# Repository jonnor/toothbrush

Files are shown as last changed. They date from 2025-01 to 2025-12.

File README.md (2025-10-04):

# Automatic toothbrush timer

This toothbrush timer tracks how long you spend on actively brushing your teeth.
It uses an accelerometer to measure motion, and analyzes it using a simple machine learning model.
The device helps you get to the 2 minute mark, which is the recommend duration!

This is a demo project for [emlearn-micropython](https://github.com/emlearn/emlearn-micropython),
a library efficient Machine Learning and Digital Signal Processing for [MicroPython](https://micropython.org/).
The intent is to be a fun and simple, but realistic application, of machine learning on microcontrollers,
in the area of Human Activity Recognition.

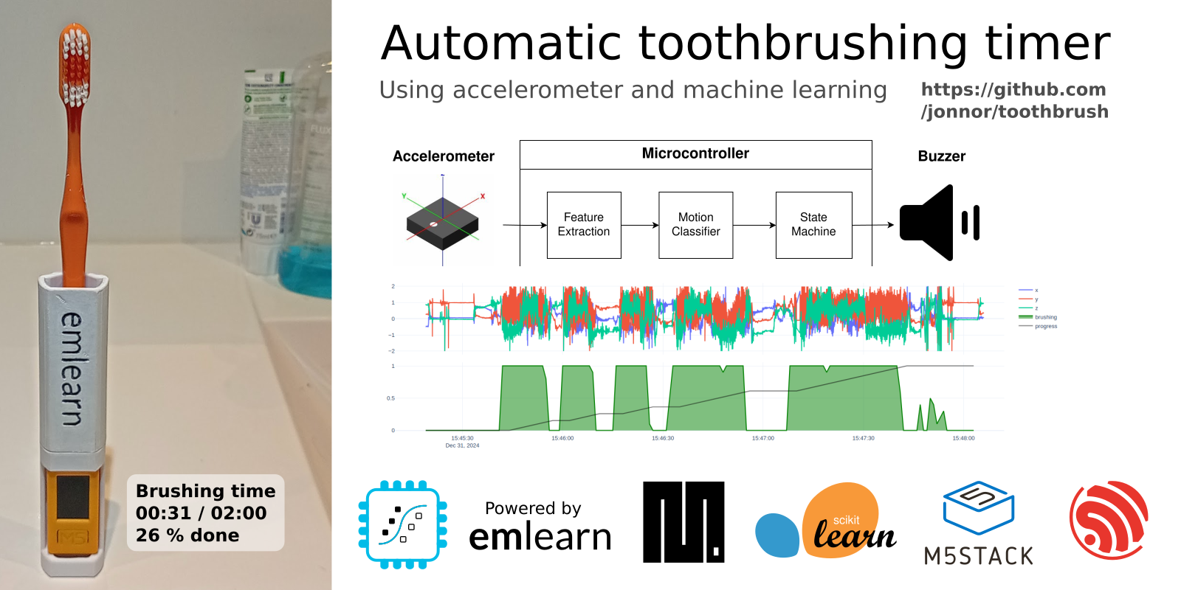
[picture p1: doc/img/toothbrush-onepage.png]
One-page visual explainer


## In use

Here is a [short demo video](https://www.youtube.com/shorts/U8TeewQ9t-k).

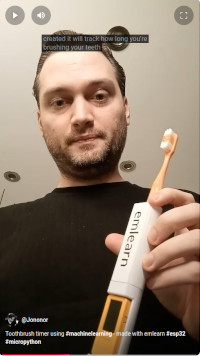
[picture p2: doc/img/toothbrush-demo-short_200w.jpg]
Demo video (https://www.youtube.com/shorts/U8TeewQ9t-k)


## Status
***Proof of Concept***. Tested working on device.

- Firmware is complete and functional
- Basic documentation on how to reproduce exists
- Software and training pipeline *needs some cleanup*

For more details, see [TODO.md](./doc/TODO.md)

## License
MIT

## Hardware

To assemble the device, one needs the following.

- [M5Stick C PLUS2](https://shop.m5stack.com/products/m5stickc-plus2-esp32-mini-iot-development-kit) from M5Stack
- 3d-printed toothbrush holder. [.STL export](mechanics/toothbrush-handle-print.stl) | [FreeCAD project](mechanics/toothbrush-handle.FCStd)
- Zipties
- Double-sided tape

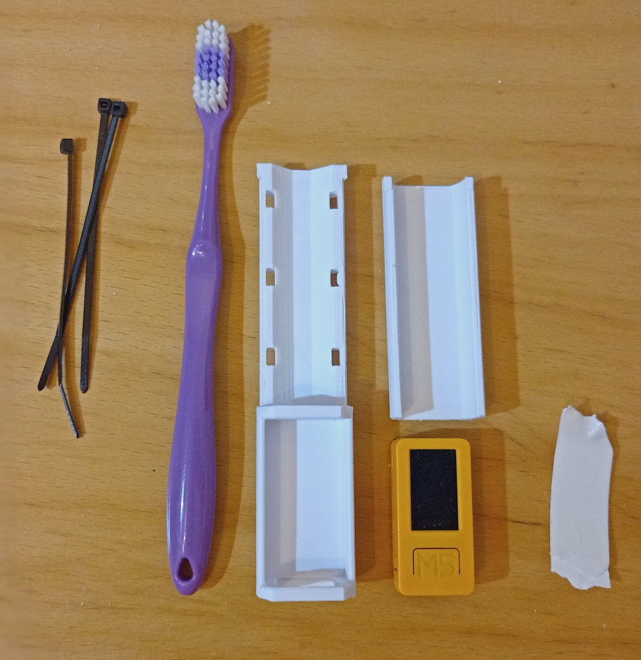
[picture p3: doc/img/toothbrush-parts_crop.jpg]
Parts before assembly
.

#### Stand

There is also an optional stand for a magnetic charging connector.
It uses a [Plexgear Magnetic USB-C adapter](https://www.kjell.com/no/produkter/kabler-og-kontakter/usb-kabler/plexgear-magnetisk-usb-c-adapter-p44923).
Hopefully something similar can be found online.

[FreeCAD project](mechanics/toothbrush-stand.FCStd)

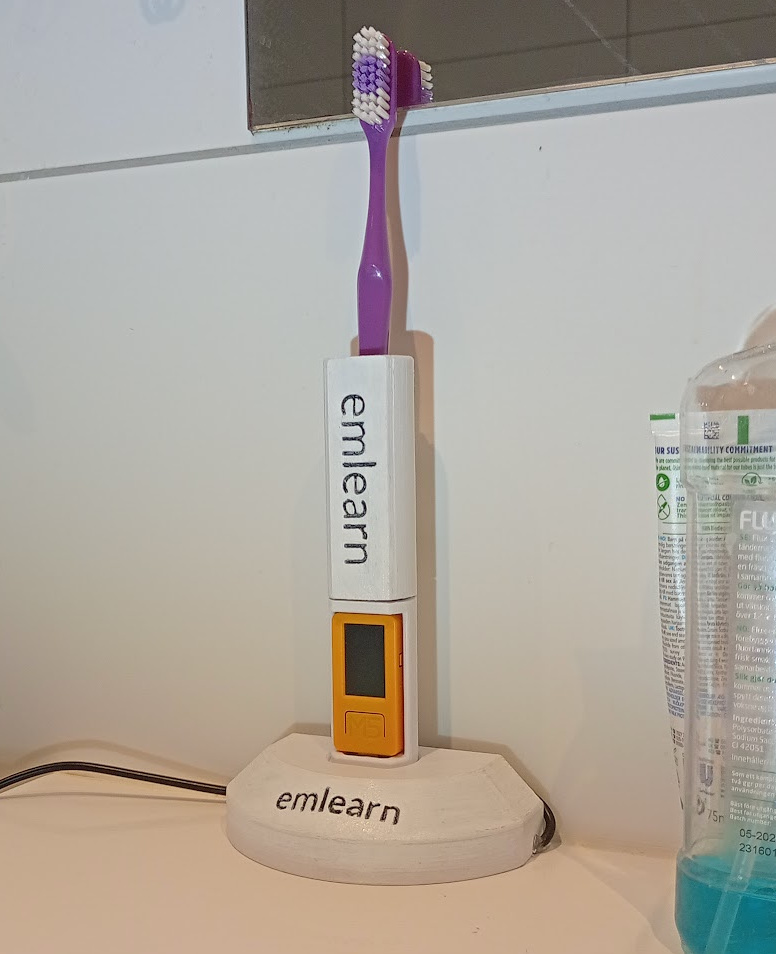
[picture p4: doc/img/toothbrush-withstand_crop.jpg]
Toothbrush with stand
.

## How it is built

The code that runs on device is found in [firmware/](./firmware).
The code used on PC to train machine learning model is found in [software/](./software)

#### Data recording

To record data we used the `har_record.py` script from [emlearn-micropython har_trees example](https://github.com/emlearn/emlearn-micropython/tree/master/examples/har_trees). 
We also recorded video of the brushing activity using a mobile phone.
This was used to establish the ground truth.
See [doc/data_collection.md](doc/data_collection.md) for details.

The raw data from device is stored in `data/jonnor-brushing-1/har_record/`.

#### Data labeling

We use [Label Studio](https://labelstud.io) to annotate the videos.
The labeling annotation definition can be found in [doc/labeling.xml](doc/labeling.xml).

The labeled data should be exported as .CSV file.

#### Data set preparation

When the data recording and data labeling has been completed, the data can be combined into a dataset.

```
FIXME: clean up these steps. Move from notebooks into .py files
```

The output goes to `data/jonnor-brushing-1/combined.parquet`.

#### Model training

To train the model we used the `har_train.py` script from [emlearn-micropython har_trees example](https://github.com/emlearn/emlearn-micropython/tree/master/examples/har_trees).
```
MIN_SAMPLES_LEAF=0.20,0.30 python har_train.py --dataset toothbrush_jonnor --window-length 50 --window-hop 50
```

#### Firmware

The firmware has the following overall architecture:

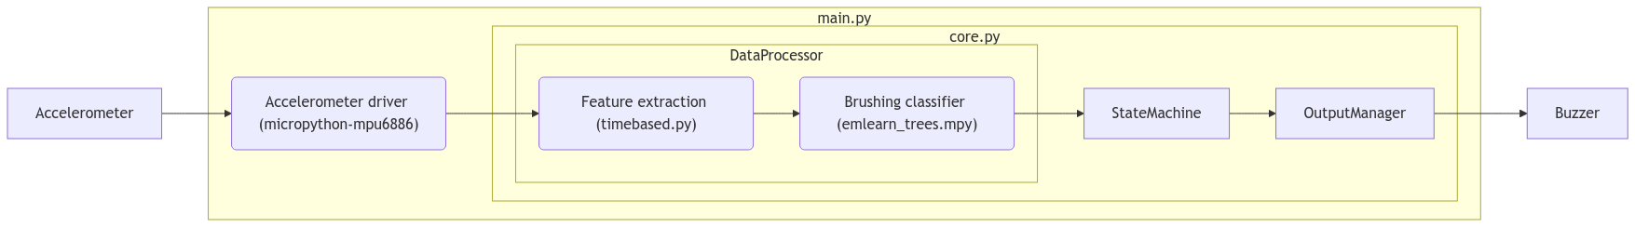
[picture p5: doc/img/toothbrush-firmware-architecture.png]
Firmware architecture diagram


Here is the states of the state machine, that defines the overall behavior of the device:
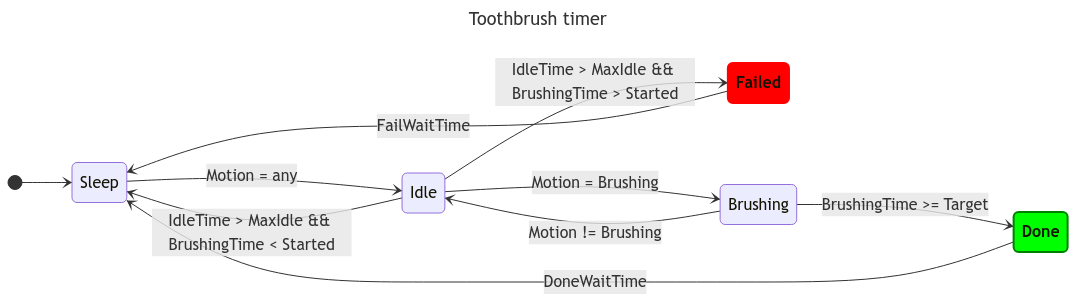
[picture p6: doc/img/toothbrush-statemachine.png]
State machine diagram


## Installing

#### Development environment

You must have Python 3.10+ installed.
Using a virtual environment is recommended.

Install project dependencies

```
pip install -e .
```

## For M5Stack M5Stick C PLUS 2 

Flash device with MicroPython for ESP32

```
mpflash flash --version 1.24
```

Copy dependencies to device

```
mpremote mip install https://emlearn.github.io/emlearn-micropython/builds/master/xtensawin_6.3/emlearn_trees.mpy
mpremote mip install github:jonnor/micropython-npyfile
mpremote mip install github:jonnor/micropython-mpu6886
mpremote mip install https://github.com/emlearn/emlearn-micropython/raw/refs/heads/master/examples/har_trees/timebased.py
mpremote mip install https://github.com/emlearn/emlearn-micropython/raw/refs/heads/master/examples/har_trees/recorder.py
```

## For XIAO BLE Sense NRF52840 

Flash device with MicroPython

```
TODO: provide pre-built firmware
```

Copy dependencies to device
```
mpremote mip install --target lib github:jonnor/micropython-npyfile
mpremote mip install --target lib https://github.com/emlearn/emlearn-micropython/raw/refs/heads/master/examples/har_trees/timebased.py
mpremote mip install --target lib https://github.com/emlearn/emlearn-micropython/raw/refs/heads/master/examples/har_trees/recorder.py
mpremote cp firmware/lsm6ds.py :lib/
```

#### Copy application to device

Copy the firmware files
```
mpremote cp firmware/core.py firmware/buzzer_music.py firmware/process.py firmware/brushing.trees.csv firmware/main.py :
```

Start the application and observe log
```
mpremote run firmware/main.py
```

Restart device, will disconnect log
```
mpremote reset
```

## Developing

#### Running firmware tests on PC

With MicroPython Unix port, one can run the firmware tests on PC.

```
micropython firmware/test_toothbrush.py
```

#### Running firmware tests on device

```
TODO: check tests on device, document how to run
```

#### Training model

```
TODO: document how to run
See the Gitlab CI actions
```

#### Modifying dataset

```
See doc/data_collection.md
```

#### Porting to other devices

All the hardware-specific code is located in `main.py`.
So modifying that is all that should be needed to adapt to another device.
If there is no buzzer with PWM, you may also want to change `OutputManager`.

Note that the accelerometer driver should use the FIFO,
to enable sampling data independently from the firmware execution. 
[More information](https://github.com/orgs/micropython/discussions/15512).

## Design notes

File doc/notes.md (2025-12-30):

# Sound design

https://onlinesequencer.net

Online Sequencer:923227:0 C5 1 43;2 D#5 1 43;1 D5 1 43;4 F5 1 43;5 F#5 1 43;6 G5 1 43;8 A5 1 43;9 B5 1 43;10 C6 1 43;12 D6 1 43;13 D#6 1 43;14 F6 1 43;17 C6 1 43;18 G5 1 43;19 E5 1 43;21 C5 4 43;:

# Hardware support

MicroPython on Zephyr for XIAO BLE Sense NRF52840

Need to have Zephyr 4.2 setup, and a virtualenv with `emlearn` installed.

In MicroPython repository

```
cd ports/zephyr/zephyrproject-4.2
source venv/bin/activate
west build --pristine -b xiao_ble/nrf52840/sense .. -- -DUSER_C_MODULES=/home/jon/projects/micropython/ports/zephyr/emlearn-micropython/src/micropython.cmake
```

With the `xiao-ble-sense-3` branch.
Includes MRs for

- https://github.com/micropython/micropython/pull/17679
- https://github.com/micropython/micropython/issues/17878

## Sensor orientation

Mostly upright, slight angle towards mounth

Original XIAO BLE NRF52
o [0.7400785, -0.045787996, 0.67096]

M5Stick C PLUS 2
o [-0.07880917, 0.8844804, -0.4598734] 1055.342

45 deg down to left
Stick
o [0.5536062, -0.8327353, 0.008475677] 1398.014

XIAO
o [-0.7513735, 0.6585, -0.0426102] 791.2596

To map XIAO to Stick orientation, need to have X,Y,Z = Y,X,-Z

# Dataset

## sss

```
python -m software.dataset.combine \
    --data ./data/xiao-test-2/har_record \
    --samplerate 104 \
    --columns gyro_x,gyro_y,gyro_z,acc_x,acc_y,acc_z \
    --default-date 2024-09-20 \
    --out combined2.parquet
```

ss
```
python -m software.dataset.labeling_prepare --data data/xiao-test-2/har_record/ --out data/xiao-test-2/for_labeling --samplerate 104 --columns gyro_x,gyro_y,gyro_z,acc_x,acc_y,acc_z --default-date 2024-09-20
```

# Data

#### Dataset for toothbrushing activity using brush-attached and wearable sensors
https://www.sciencedirect.com/science/article/pii/S2352340921005321
https://data.mendeley.com/datasets/hx5kkkbr3j/1
https://prod-dcd-datasets-cache-zipfiles.s3.eu-west-1.amazonaws.com/hx5kkkbr3j-1.zip

Hussain et. al, 2021

Toothbrushing data for 120 sessions performed by 22 participants (11 males, 11 females).
The data was collected using two IMU devices from Mbientlab Inc.
One device was attached to the brush handle, while the other device was used as wearable (wristwatch on the brushing hand).
The participants brush their teeth for around two minutes in each session following a pre-given sequence.
16 sub-activities, corresponding to location being brushed, done in pre-defined order.

! no explicit labels.

235 MB total.

#### Dataset: Toothbrushing Data and Analysis of its Potential Use in Human Activity Recognition Applications
October 22, 2020

Paper
https://dl.acm.org/doi/epdf/10.1145/3419016.3431489
https://researchers.mq.edu.au/en/publications/toothbrushing-data-and-analysis-of-its-potential-use-in-human-act/

Dataset download
https://zenodo.org/records/4118900

Git repository with code
https://github.com/icl-mq/toothbrushing-dataset

Zawar Hussain, David Waterworth, et. al
Macquarie University

17 participants when they brushed their teeth over one week in 5 different locations.
62 toothbrushing sessions for each of the brush-attached and wearable sensor approaches, using both electric and manual brushes.
The average duration of each session is 2 minutes.
One sensor device was attached to the handle of the brush while the other was worn by the participants as a wrist-watch.
We collected the data from a 3-axis accelerometer and a 3-axis gyroscope at a 200 Hz sampling rate.

3 participants used an electric brush while 14 participants used a manual brush.

Has both electric toothbrush and manual.

Contains labels in form of `labels.json` files.
Annotated with the 16 sub-activities (areas of mouth) in the toothbrushing activity.
Used semi automated labeling.
Estimated approximated brush orientation from raw accelerometer axis and the cumulative sum of the gyroscope axis, and then applied change point analysis.

! Risk of incorrect labels. Not verified against video etc

! Paper did not do subject or session leave-one-out. Accuracy is overestimated.

! some sessions are unlabeled. Are included in dataset

#### ROBAS-UCLA/Toothbrushing-region-detection 

Data and code
https://github.com/ROBAS-UCLA/Toothbrushing-region-detection

! Zenodo upload is empty. Github repository seems to have data.

Paper:
Monitoring Brushing behaviors using Toothbrush Embedded Motion-Sensors
https://www.researchgate.net/publication/370381712_Monitoring_Brushing_behaviors_using_Toothbrush_Embedded_Motion-Sensors
April 2023
Mahmoud Essalat, Oscar Hernan Madrid Padilla, Vivek Shetty, Gregory Pottie

Dataset of 187 brushing sessions. Including free-form brushing.
12 participants.

Propose a three-stage method to detect the teeth surfaces brushed during a session, into nine brushing regions.
 consisting of: pre-processing, brush transition time detection, and time-series classification.

Compared 3 different models. Feature engineering, LSTM on raw samples.

Compared to existing Hussain2020 dataset.
Found their dataset was 5-10 percentage points F1 score more difficult.

Compared random k-fold to leave-one-subject-out and leave-one-session-out.
! F1 scores on subject-out as low as 58% with best method.

! nice plots of Euler Angles roll/yaw wrt locations, for a few subjects.
Shows that the angles are different for different participants.

#### UMATBrush
https://www.sciencedirect.com/science/article/pii/S2352340925007048
https://figshare.com/articles/dataset/UMATBrush_Traces/28955756
October 2025.

F.J. González-Cañete, E. Casilari
Departamento de Tecnología Electrónica, Telecommunication Research Institute (TELMA), Universidad de Málaga

Dataset characteristics

- 4 experimental subjects during their normal life
- using 3 commercial smartwatches
- Over 5 hours of toothbrushing activity, and over 140 toothbrushing sessions
- long periods of monitoring of the subjects during their daily lives, over 200 hours in total
- binary labelled as either corresponding or not to a toothbrushing session
- Tri-axial accelerometer, no gyro
- Samplerate approximately 100 Hz

2.92 GB download.
Stored as .CSV files.

Table 1. Existing available datasets with sensor data collected with wrist-worn sensors during toothbrushing activities.
! Lists 13 datasets, however vast majority are general Activities of Daily Living (ADL).
Toothbrushing is the one of 10-30 activities.
Usually recorded with a generic device, like a smart watch.

Reports toothbrushing power being typically around 4-5Hz.

Notes limited number of participants.
Expanding the participant pool to cover different age groups and dental conditions would help
improve the representativeness and applicability of the dataset.

## Hardware

- Needs accelerometer/IMU.
- And some way of notifying user. LED and/or buzzer.

For prototyping the M5StickC can be used.
A bit bulky, but workable.

Then the `dml20m` hardware would be used to actually demonstrate the 1 USD TinyML concept.

## References

#### Development and evaluation of the “Toothbrushing Timer with Information on Toothbrushes” application: A prospective cohort pilot study
https://pmc.ncbi.nlm.nih.gov/articles/PMC10728532/

A mobile phone app to help users ensure appropriate toothbrushing time and learn about the beneficial characteristics of toothbrushes

#### Separating Movement and Gravity Components in an Acceleration Signal and Implications for the Assessment of Human Daily Physical Activity

We aimed to evaluate five different methods (metrics) of processing
acceleration signals on their ability to remove the gravitational component of acceleration during standardised mechanical
movements and the implications for human daily physical activity assessment.

Euclidian norm minus one (ENMO),
Euclidian norm of the high-pass filtered signals (HFEN),
HFEN plus Euclidean norm of low-pass filtered signals minus 1 g (HFEN+)

#### Gravity subtraction

Should establish the initial gravity vector for calibration.
When standing in holder.

To leave out the gravity vector from the accelerometer value, you need to rotate the accelerometer vector to the earth frame using a rotation matrix or quaternion which can be calculated from accelerometer, gyroscope, and magnetometer.
After you rotate the vector to the earth frame you can subtract the (0, 0, g)^T vector to take out the gravity.
You can rotate the resulted vector to the body frame again by multiplying the inverse matrix of the rotation matrix that you have used before

https://math.stackexchange.com/a/1746199/1519080 
Python/numpy code

https://howtomechatronics.com/tutorials/arduino/how-to-track-orientation-with-arduino-and-adxl345-accelerometer/
https://www.allaboutcircuits.com/technical-articles/how-to-interpret-IMU-sensor-data-dead-reckoning-rotation-matrix-creation/

Freescale AN3461: Tilt Sensing Using a Three-Axis Accelerometer

https://josejuansanchez.org/android-sensors-overview/gravity_and_linear_acceleration/README.html
Simple java code using 

ahrs Python library has excellent explanations of the various methods.
Using different combinations of accel/gyro/magnetometer.
https://ahrs.readthedocs.io/en/latest/filters.html
https://ahrs.readthedocs.io/en/latest/filters/tilt.html
https://ahrs.readthedocs.io/en/latest/filters/complementary.html

#### Gravity estimation using lowpass

A Public Domain Dataset for Human Activity Recognition Using Smartphones. Anguita et al (2013)

> The gravitational force is assumed to have only low frequency components,
> therefore we found from the experiments that 0.3 Hz was an optimal corner frequency for a constant gravity signal.
! Order not specified. Their other filter was 3rd order.

In "A benchmark for domain adaptation and generalization in smartphone-based human activity recognition"
https://www.nature.com/articles/s41597-024-03951-4

> The Acc can only sense the total acceleration, so some procedures must be performed to separate the body and gravity acceleration.
> Several methods described in the literature are suitable for this task.
> However, the most common involves applying a high-pass Butterworth filter of low order (e.g., order 3) with a cutoff frequency below 1 Hz

In "Frequency Domain Approach for Activity Classification using Accelerometer"
Chung et al, 2028

> Elliptical IIR High Pass filter (HPF) of seventh order with 0.5 Hz cutoff frequency
was used to separate the bodily accelerations from the gravity accelerations.

## Existing products

There are timers.
Especially targetting kids.
Some are using an hourglass principle using colored oil.

Some are electronic using light to indicate done.

Braun has "Genius X" series.
https://www.oralb.co.uk/en-gb/product-collections/genius-x
An electric toothbrush with "Artificial Intelligence".
Tracks where you brush in your mouth.

## Ideas

How to get people to actually do their toothbrushing?
Touge in cheek approaches.

- Tooth-a-ma-gotchi. It will starve if you do not brush enough
- Shamification-gamification. If you do not brush enough, it will tell your mother/partner/dentist. Communicate via BLE to phone
- Strava for your teeth. Posts to social media bragging about the "course" that you completed

## Asides

#### Adverserial usage

If someone is trying to fool the device that they are actually brushing their teeth,
can we actually separate that from actual toothbrushing?
Like vigorous shaking. At approximately the right periodicity.
At approximately the right angle even?
Probably not...
But including some roughly similar data from other semi-energetic activities might be a good check for robustness.

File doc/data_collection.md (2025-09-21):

# Data collection

## Overall design

Ideally one would want to have multiple persons perform the activities,
and test/train splits would be split on subject.
Number of subjects would preferably be 10+.

The next best thing is to have one person record separate sessions,
and test/train splits are done using the session.
Must have at least 4 sessions. Ideally would want 10+ sessions.

Each brushing session should be around 3 minutes long, with around 2 minutes of actively brushing teeth.
The rest of time is filled with "pauses" with activities which may plausibly appear
in and round the activity of brushing ones teeth.

### Protocol

Before session

- Setup device with har_record.py from har_trees emlearn-micropython example.
- Update the device RTC. `mpremote rtc --set`

For each session

- Start video recording on mobile phone
- Start data recording by holding the M5 button. Light should turn red
- Start with toothbrush standing stationary on surface/stand. 5 seconds
- Tap toothbrush 5 times onto flat service (timesync marker)
- Brush teeth like normally
- Take a number of pauses of 5-10 seconds duration. Do some pause activity (see below)
- After around 3 minutes, can stop
- Stop data recording
- Stop video recording

### Example of pause activities

- Swap toothbrush between hands.
- Hold toothbrush completely still in mouth
- Take toothbrush out of mouth to talk
- Put toothbrush down on surface, pick up again
- Swing arms down
- Walk around with toothbrush in hand
- Stretch with arms overhead
- Drop the toothbrush in the sink
- Rinse the toothbrush
- Put more toothpaste on toothbrush
- Other (subject decides)
- Check something on the face in the mirror
- Talk to someone
- Drink water from tap
- Turn tap off/on
- Inspect/poke at teeth

### Other activity data

NOTE: not used

### Example of other activities

- Walking around indoor, toothbrush in hand
- Walking in stairs, toothbrush in hand
- Playing swords with toothbrush
- Sitting down/up, toothbrush in hand
- Dropping toothbrush onto surface
- Throwing toothbrush onto surface
- Toothbrush lying on surface
- Throwing toothbrush into the air, flipping
- Tapping on toothbrush
- Inspecting toothbrush
- Walking with toothbrush in backpack
- Driving with X in backpack
- Biking with X in backpack

### Potential confusors

Things that have similar data characteristics.
Especially those that also can be expected to co-occur in ordinary real-world usage.

Periodic alternating motion with 2-5 Hz.
Fast walk / jogging / running?

## Video recording

Use "Open Camera" on Andoid phone.

Video settings
```
Resolution                  720p
Orientation.                Portrait
Framerate.                  30 fps
Format.                     MPEG4 H264
Bitrate.                    3 Mbps
```

Estimated 25 MB per 1 minute, 75 MB pre 3 minute session.
Still just a few GB for 20 sessions.

Going down to 1 Mbps gave noticably worse results.

! check that this open nicely in Label Studio.

## Dataset pipeline structure

```
Raw data:

    Session metadata            /sessions.csv
    Sensor data.                /har_record/$session/*.npy
    Video from phone.           /videos/$session/X.mkv

For labeling

    Video. One video (URL) per session
    Timeseries. One CSV per session
    Task list. CSV/JSON with one row per session. URL for video and timeseries
    Annotation template

After labeling

    Labels from Label Studio.   /labels/project.csv

After combining

    Combined data               /combined.parquet
```

## Session metadata

```
participant
device
location
brush
```

## Video access

! videos need to be on a URL to be accessible.
Can be localhost if using Label Studio locally?

Not all participants may allow open access to the video.
Generally this should be something authenticated.
Might need to use pre-signed / anonymous URLs.

How to identify data in the Label Studio output?
Session identifiers should be in the video/timeseries URLs

# Aligning / time syncronization

Open video, find location of the first sync (in seconds)

??? Where does the time syncronization happen
Would want to do before

https://labelstud.io/templates/timeseries_audio_video
! Must set frameRate

# Labeling notes

Labeling precision target.
Better than 1 second.
Not needed as good as 100 ms.

# Video notes

Used this to get a more compressed video file.
15 MB per 3 minutes.

Recommendations by Label Studio
https://labelstud.io/tags/video#Video-format
! also specify -r 30 for constant-frame-rate

ffmpeg -i input.avi -c:a copy -vf "scale=-2:720" -c:v libx264 -pix_fmt yuv420p -crf 23 output.mkv

ffmpeg -ss 00:03:00 -i input.mkv -c copy output.mp4

Download links in Google Drive

https://drive.google.com/uc?export=download&id=FILEID

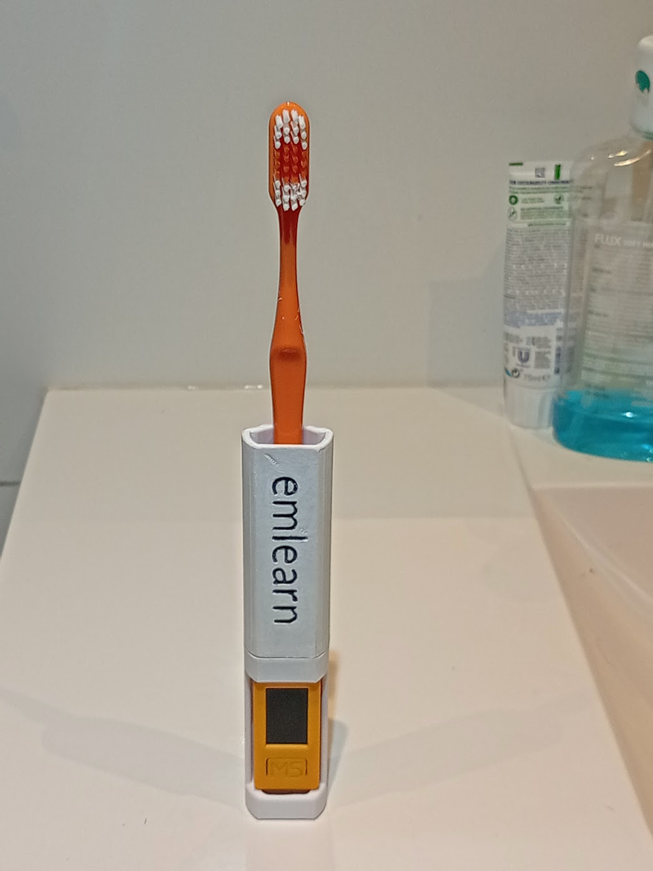
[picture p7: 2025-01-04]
doc/img/toothbrush-only.jpg

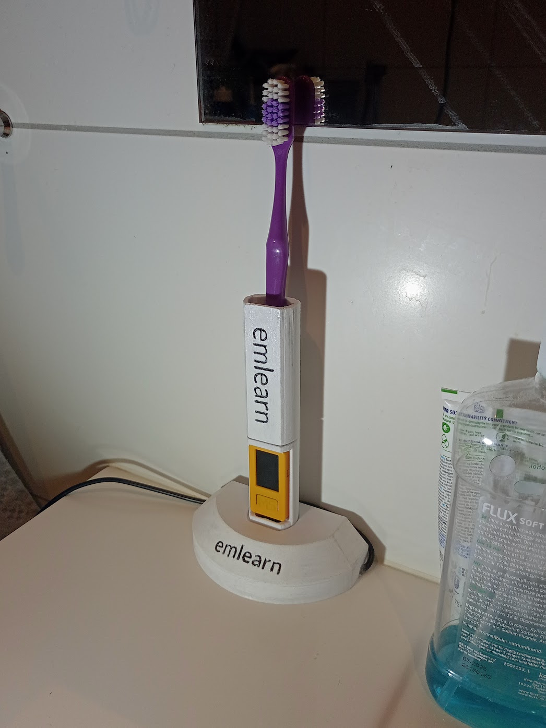
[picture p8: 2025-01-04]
doc/img/toothbrush-withstand2.jpg

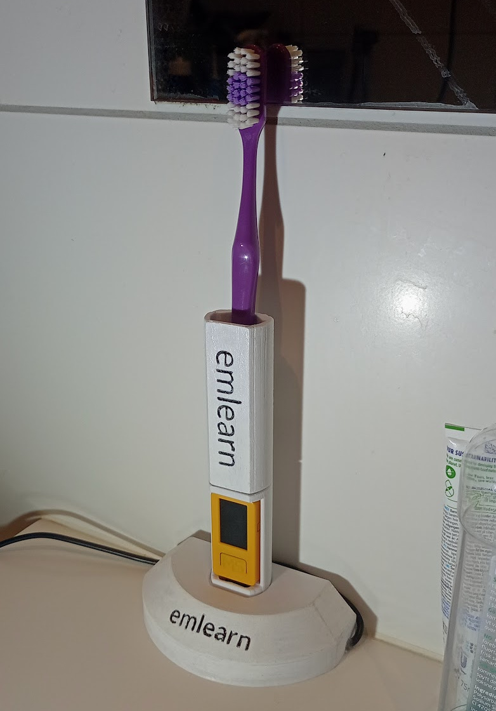
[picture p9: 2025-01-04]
doc/img/toothbrush-withstand2_crop.jpg

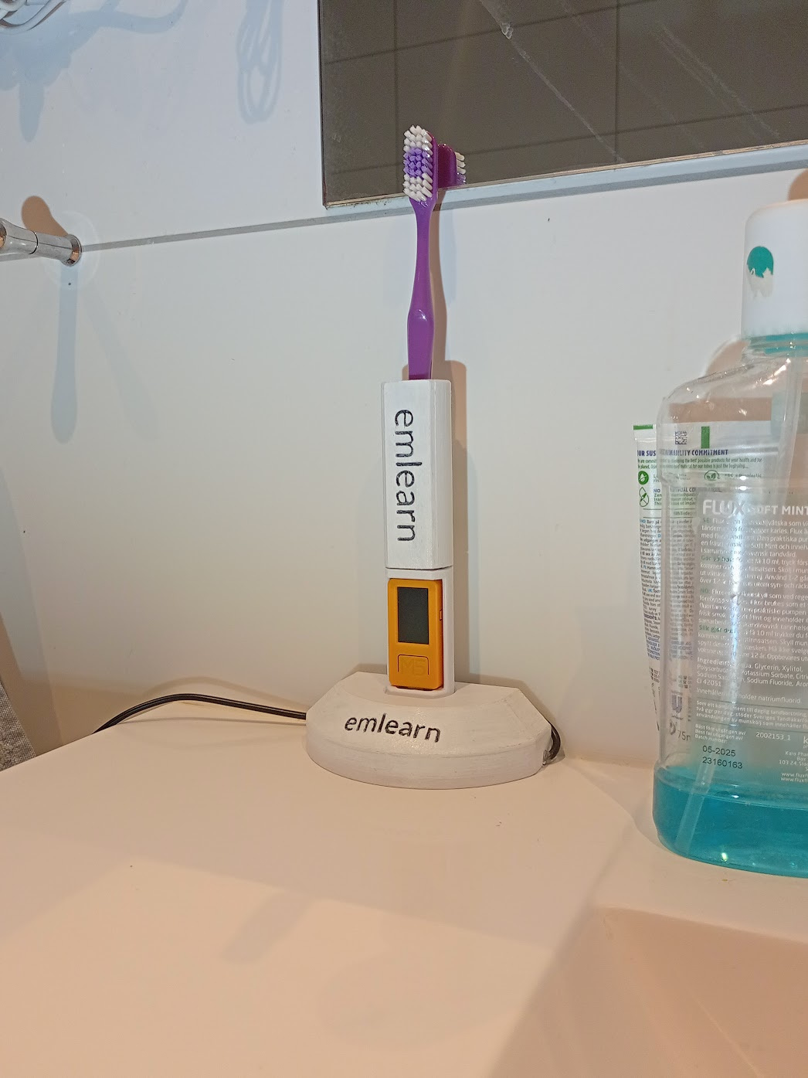
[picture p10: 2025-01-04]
doc/img/toothbrush-withstand.jpg

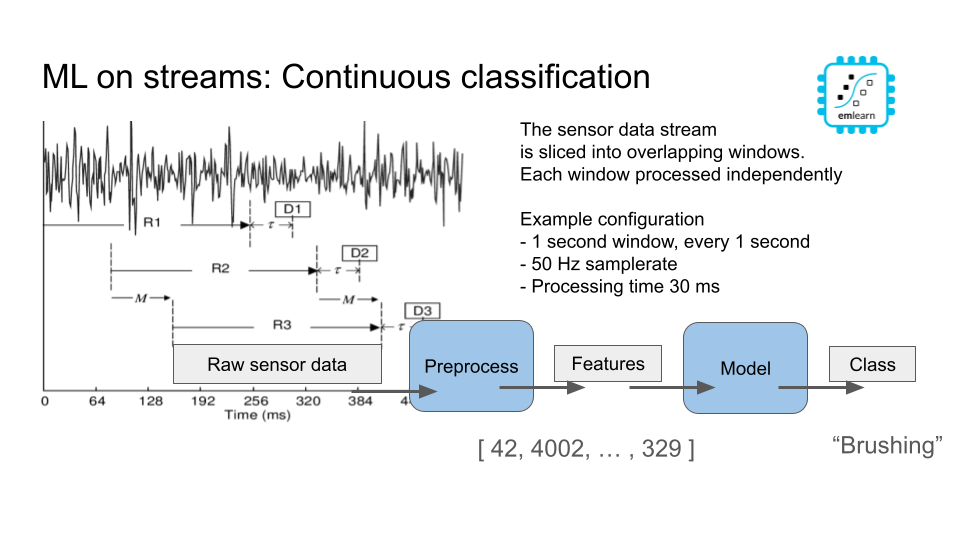
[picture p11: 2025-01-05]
doc/img/toothbrush-continious-classification.png

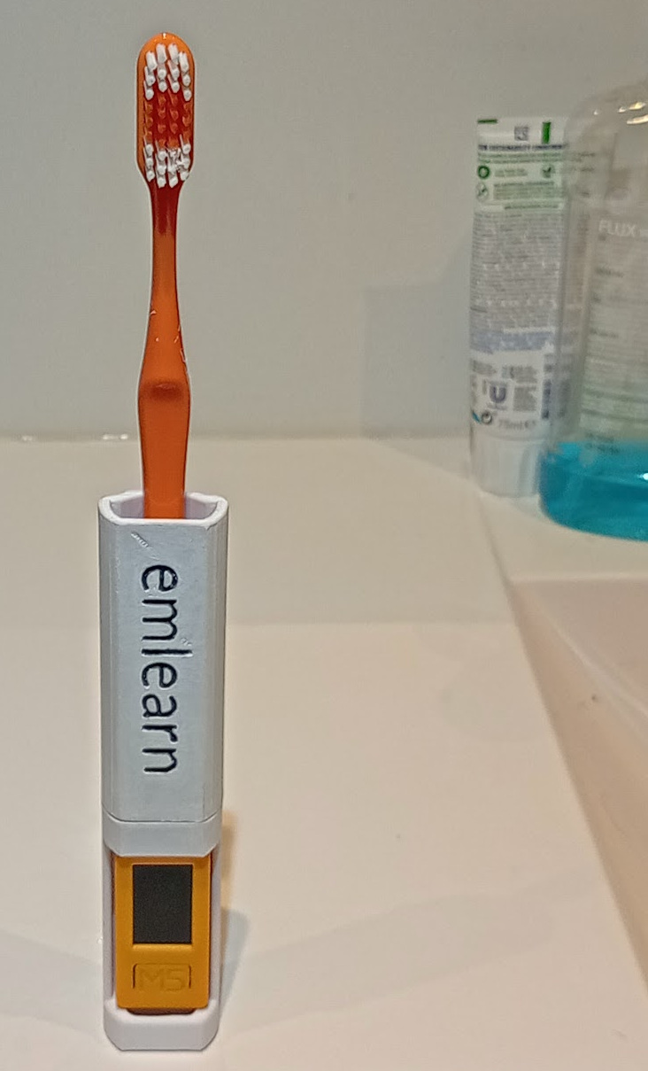
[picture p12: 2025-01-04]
doc/img/toothbrush-only_crop.jpg

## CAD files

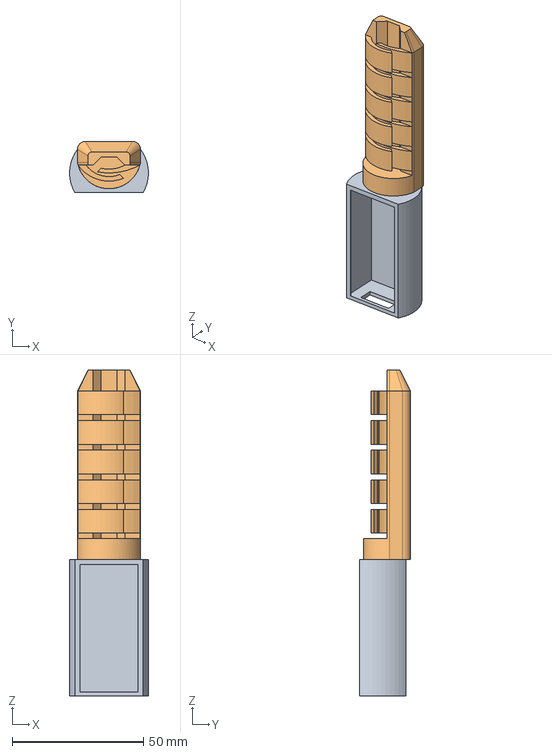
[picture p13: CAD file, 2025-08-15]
mechanics/toothbrush-flex.FCStd
30.0 x 19.5 x 124.0 mm

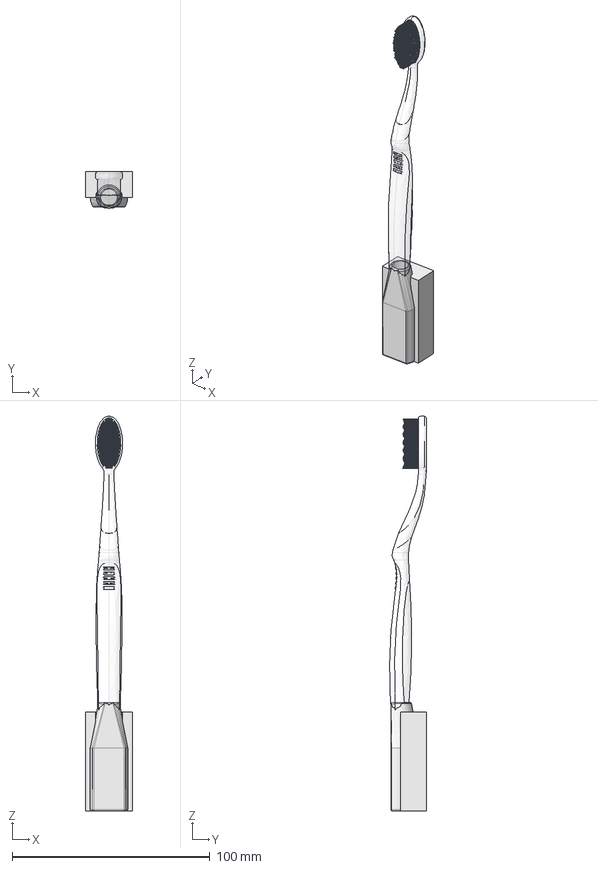
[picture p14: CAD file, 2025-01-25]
mechanics/toothbrush-dml21m2.FCStd
24.0 x 18.6 x 200.0 mm
ref brush surfacing

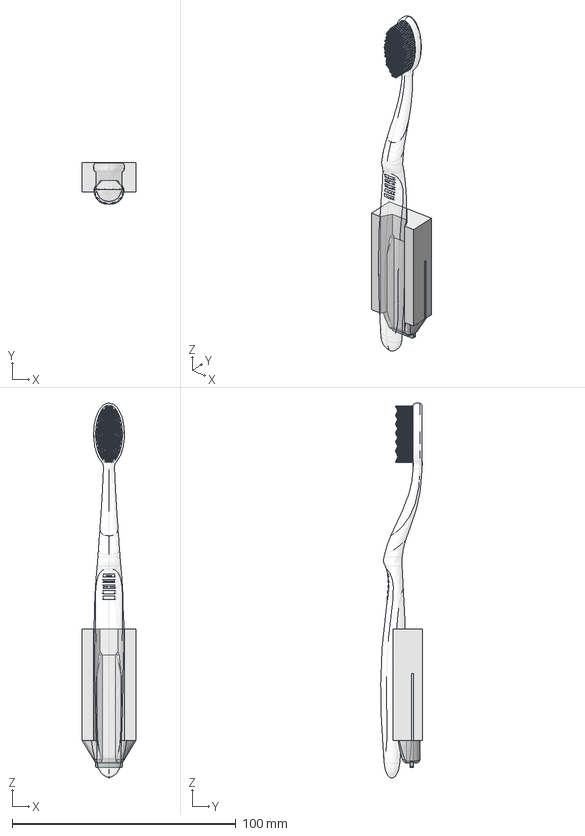
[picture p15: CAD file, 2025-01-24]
mechanics/toothbrush-dml20m.FCStd
24.0 x 18.6 x 167.7 mm
ref brush surfacing
dml20m_PCB

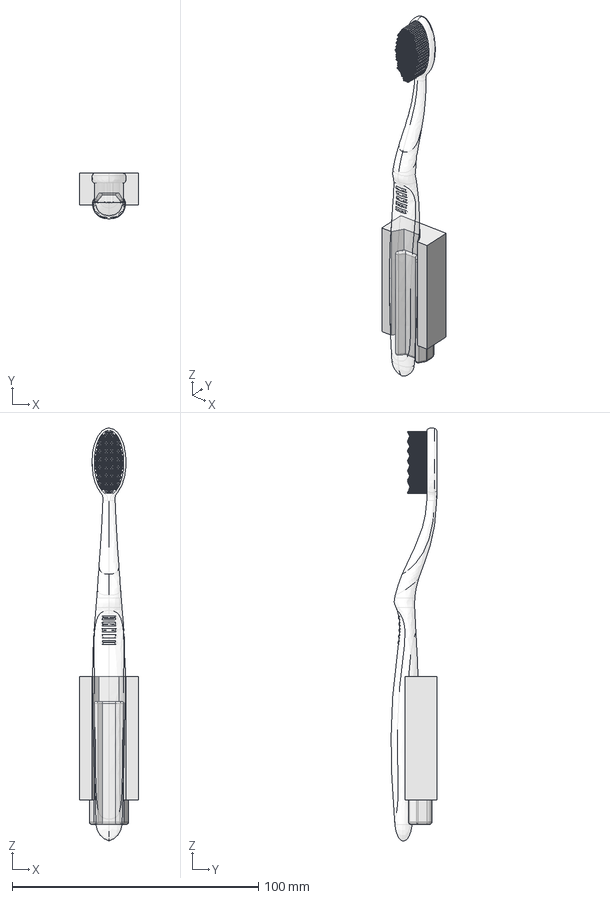
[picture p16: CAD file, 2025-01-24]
mechanics/toothbrush-dml21m.FCStd
24.0 x 18.6 x 167.7 mm
ref brush surfacing

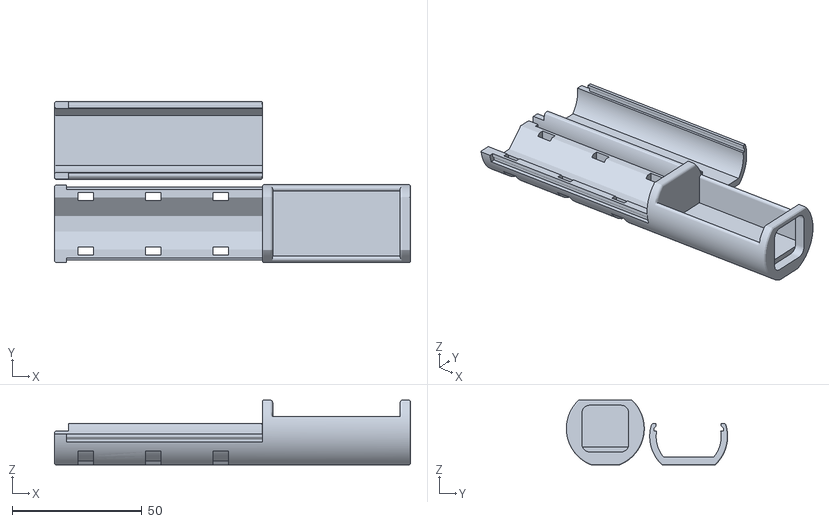
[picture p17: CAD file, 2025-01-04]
mechanics/toothbrush-handle-print.stl
137.0 x 62.1 x 25.0

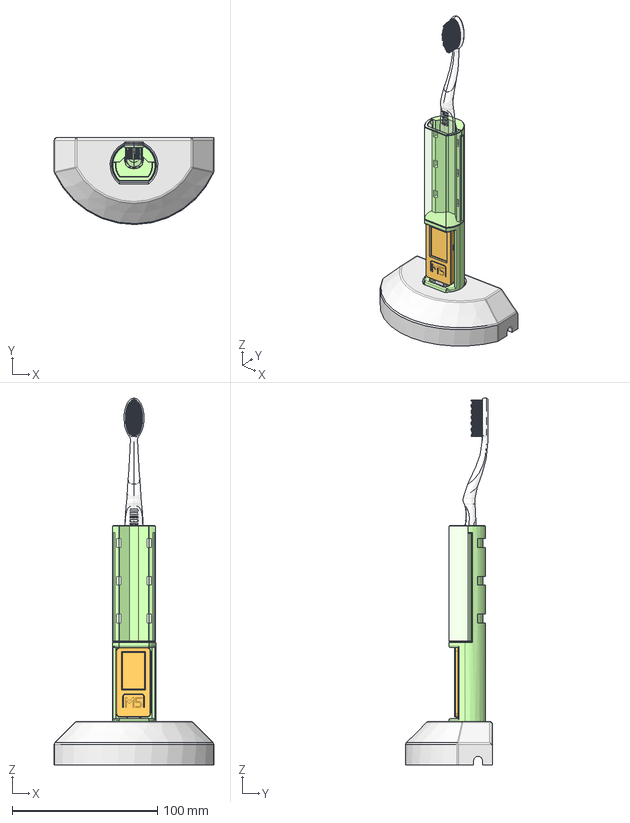
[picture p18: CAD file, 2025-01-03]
mechanics/toothbrush-stand.FCStd
110.0 x 60.0 x 253.0 mm
ref brush surfacing
lid-b
Grove socket v7
ConPins
PcbPins
Mold
Frame
handle-b

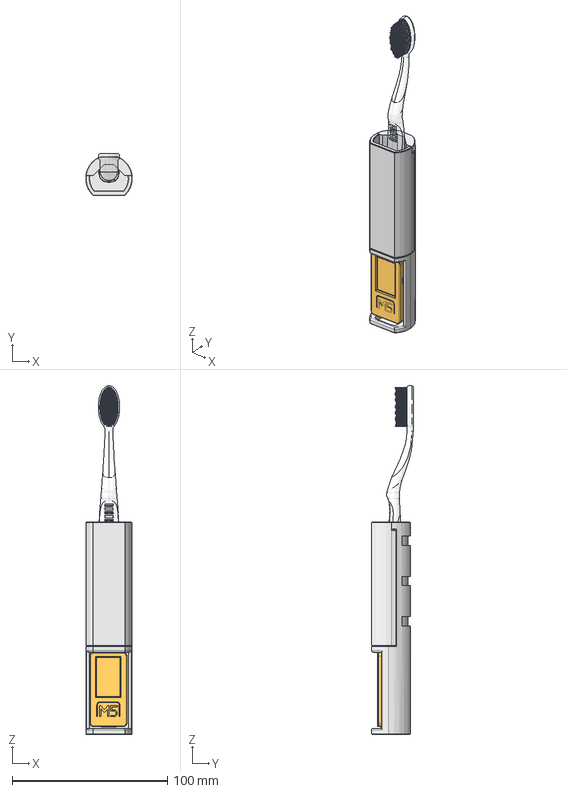
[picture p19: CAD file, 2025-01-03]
mechanics/toothbrush-handle.FCStd
30.0 x 27.0 x 225.0 mm
handle-b
Grove socket v7
ConPins
PcbPins
Mold
Frame
lid-b
ref brush surfacing

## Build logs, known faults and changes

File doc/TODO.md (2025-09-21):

# TODO

## Flex handle

- Record new demo video.
Previous version needed to use zipties, was quite large.
Easy mounting onto toothbrush, without any tools.
Tested on variety of brushes I could find in the store, from thinnest to the thickest.
Printed in flexible TPU, using NinjaFlex

## Zephyr firmware version

Using XIAO BLE Sense NRF52840.
Initially with MicroPython, but with an aim to have pure C version.

#### Mini dataset v2

- Get timeseries/video to work in LabelStudio
- Record at least 3 sessions
- Label all the sessions
- Test data using the dataset and training pipelines
- Improve the notes in [data_collection.md](./data_collection.md)

#### Running in C

Related
https://github.com/jonnor/zephyr/blob/emlearn-sensor-readout/samples/modules/emlearn/sensor_reader/src/main.c

- Implement gravity separation using eml_iir
- Fixup the C feature extraction code.
- Support running C feature extraction in pipeline. CSV, gcc, and subprocess
- Setup/run evaluation pipeline on validation/testset on device. CSV
- Test live predictions on device

Later

- Port LSM6DS3 FIFO driver to C/Zephyr
- Use .npy instead of .csv
- Holder. Try add in emlearn logo on bottom

## Multi-participant dataset

Ref [data_collection.md](./data_collection.md)

- Get volunteers that are interested in participating
- Do a trial run at home
- Schedule a time to do the data recording

## Pipeline improvements

- Setup quantitative evaluation of the time tracking.
Note, some starts in the notebooks.
Cut out random selections of time-sections.
Respect train/test folds.
- Implement tests for state machine for sad case

## More features

Bluetooth connectivity

- Send prediction data over BLE. To phone
- Support sending sensor data over BLE.
For easier data collection.
- Make a small PoC application on phone that shows data

Power management

- Add battery voltage/power/percent tracking
- Enable sleeping, test battery life

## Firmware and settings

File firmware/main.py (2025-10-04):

import machine
from machine import Pin, I2C

import gc
import time
import math
import struct
import array
import asyncio
import sys

sys.path.insert(0, 'lib/') # XXX: why not on path?

from core import StateMachine, OutputManager, DataProcessor, empty_array, clamp
from recorder import Recorder

HW_M5STICK_PLUS2 = 'm5stick-plus2'
HW_XIAO_BLE_SENSE = 'xiao-ble-sense'

is_m5stick = 'ESP32' in sys.implementation._machine
hardware = HW_M5STICK_PLUS2 if is_m5stick else HW_XIAO_BLE_SENSE

# Free memory used by imports
gc.collect()


def _test_outputs_asyncio():

    #buzzer_pin = machine.Pin(2, machine.Pin.OUT)
    #led_pin = machine.Pin(19, machine.Pin.OUT)

    # On XIAO BLE, pin 6, 26, 30 has RGB LED
    led_pin = ("gpio0", 26)
    #led_pin = ("pwm0", 0)
    # PWM1 is mapped to GPIO pins using Zephyr .overlay
    buzzer_pin = ("pwm0", 1)

    sm = StateMachine()
    states = sm._state_functions.keys()
    out = OutputManager(buzzer_pin=buzzer_pin, led_pin=led_pin)

    for state in states:
        sub_states = [0]
        if state == 'brushing':
            sub_states = list(range(0, 4))
        for sub in sub_states:
            print('test-output-state', state)
            await out.run(state, sub)
            asyncio.sleep_ms(1000)

def test_outputs():
    asyncio.run(_test_outputs_asyncio()) 

def deinterleave_samples_xiao(buf : bytearray,
        xs, ys, zs, rowstride=6, offset=0, format='>hhh'):
    """
    Convert raw bytes into X,Y,Z int16 arrays
    """
    assert (len(buf) % rowstride) == 0
    samples = len(buf) // rowstride
    assert len(xs) == samples
    assert len(ys) == samples
    assert len(zs) == samples

    for i in range(samples):
        idx = offset + (i*rowstride)
        x, y, z = struct.unpack_from(format, buf, idx)
        xs[i] = y
        ys[i] = x
        zs[i] = -z

def deinterleave_samples_m5stick(buf : bytearray,
        xs, ys, zs, rowstride=6, offset=0, format='>hhh'):
    """
    Convert raw bytes into X,Y,Z int16 arrays
    """
    assert (len(buf) % rowstride) == 0
    samples = len(buf) // rowstride
    assert len(xs) == samples
    assert len(ys) == samples
    assert len(zs) == samples

    for i in range(samples):
        idx = offset + (i*rowstride)
        x, y, z = struct.unpack_from(format, buf, idx)
        xs[i] = x
        ys[i] = y
        zs[i] = z

def decode_samples(
        buf : bytearray,
        samples : array.array,
        rowstride,
        offset=0,
        format='<hhhhhh',
    ):
    """
    Convert raw bytes for gyro+accelerometer into int16 array
    """

    in_stride = rowstride
    assert (len(buf) % in_stride) == 0
    n_samples = len(buf) // in_stride

    out_stride = len(format)-1
    assert len(samples) == out_stride*n_samples, (len(samples), out_stride*n_samples)

    #view = memoryview(buf)
    for i in range(n_samples):
        idx = offset + (i*in_stride)
        values = struct.unpack_from(format, buf, idx)
        for j, v in enumerate(values):
            samples[(i*out_stride)+j] = v

def main():

    print('init-start')

    # Settings
    hop_length = 50
    window_length = hop_length

    # FIXME: standardize configuration between hardwares
    if hardware == HW_M5STICK_PLUS2:
        samplerate = 50
        accel_offset = 0 # data is AxAyAzTc
        accel_format = '>hhh'
        # FIXME: make MPU also support gyro
        bytes_per_sample = 8 
        record_format = '>hhh'
    else:
        samplerate = 52
        bytes_per_sample = 12
        accel_offset = 6 # data is GxGyGzAxAyAz
        record_format = '<hhhhhh'
        accel_format = '<hhh'

    record_enable = True
    record_duration = 20.0
    record_dir = 'har_record'
    record_class = 'brushing'
    if record_enable:
        record_samples = len(record_format) - 1
        record_buffer = array.array('h', (0 for _ in range(record_samples*hop_length))) # decoded int16
    else:
        record_buffer = None

    # working buffers
    x_values = empty_array('h', hop_length)
    y_values = empty_array('h', hop_length)
    z_values = empty_array('h', hop_length)
    chunk = bytearray(bytes_per_sample*hop_length)

    print('setup-hardware-start')

    time.sleep(1)

    # Setup hardware-specific things
    if hardware == HW_M5STICK_PLUS2:
        # pin19 is internal red LED on M5StickC PLUS2
        led_pin = machine.Pin(19, machine.Pin.OUT)
        # pin2 is internal buzzer on M5StickC PLUS2
        buzzer_pin = machine.Pin(2)

        # On M5StickC we need to set HOLD pin to stay alive when on battery
        hold_pin = machine.Pin(4, machine.Pin.OUT)
        hold_pin.value(1)

        from mpu6886 import MPU6886
        imu = MPU6886(I2C(0, sda=21, scl=22, freq=100000))
        # Enable FIFO at a fixed samplerate
        imu.fifo_enable(True)
        imu.set_odr(samplerate)

        assert imu.bytes_per_sample == bytes_per_sample,\
            (imu.bytes_per_sample, bytes_per_sample)
        deinterleave_samples = deinterleave_samples_m5stick

    elif hardware == HW_XIAO_BLE_SENSE:
        print('hardware-init-xiao-ble-sense')
        time.sleep(1)

        import lsm6ds
        # On XIAO BLE, pin 6, 26, 30 has RGB LED
        led_pin = ("gpio0", 26)
        # Using PWM on the same bank as buzzer does not work
        #led_pin = ("pwm0", 0)
        # PWM1 is mapped to GPIO pins using Zephyr .overlay
        buzzer_pin = ("pwm0", 1)

        # FIXME: use 52 Hz, and FIFO
        i2c = I2C("i2c0")
        assert samplerate == 52
        imu = lsm6ds.LSM6DS3(i2c, mode=lsm6ds.MODE_52HZ | 0b0000_1000)

        imu.fifo_enable(True)
        deinterleave_samples = deinterleave_samples_xiao


    else:
        raise ValueError("Unknown hardware: " + hardware)

    print('setup-hardware-end')

    out = OutputManager(buzzer_pin=buzzer_pin, led_pin=led_pin)

    processor = DataProcessor()
    sm = StateMachine(time=time.time(), verbose=1, prediction_filter_length=3)

    # TEST config
    sm.brushing_target_time = 20.0
    sm.idle_time_max = 5.0
    sm.brushing_started_time = 2.0

    print('init-done')

    def main_task():
        print('main-start')

        count = 0

        with Recorder(samplerate, record_duration, directory=record_dir, items_per_sample=6) as recorder:

            if record_enable:
                #recorder.delete()
                recorder.set_class(record_class)
                recorder.start()

            while True:

                count = imu.get_fifo_count()
                #print('fifo check', count)
                if count >= hop_length:
                    start = time.ticks_ms()

                    # read data
                    read_start = time.ticks_ms()

                    imu.read_samples_into(chunk)
                    deinterleave_samples(chunk, x_values, y_values, z_values,
                        rowstride=bytes_per_sample, offset=accel_offset, format=accel_format)

                    if record_enable:
                        decode_samples(chunk, record_buffer,
                            format=record_format, rowstride=bytes_per_sample)
                        recorder.process(record_buffer)

                    read_duration = time.ticks_ms() - read_start

                    process_start = time.ticks_ms()
                    motion, brushing = processor.process(x_values, y_values, z_values)
                    process_duration = time.ticks_ms() - process_start
            
                    t = time.time()
                    sm.next(t, motion, brushing)

                    print('main-inputs', t, brushing, motion, sm.state)

                    progress_state = sm.progress_state
                    progress = int(100*(sm.brushing_time / sm.brushing_target_time))
                    print('main-progress', sm.brushing_time, progress, f'{progress}%', progress_state)

                    # Update outputs
                    await out.run(sm.state, progress_state)

                    d = time.ticks_diff(time.ticks_ms(), start)
                    print('main-iter-times', d, read_duration, process_duration)

                await asyncio.sleep_ms(10)
                #machine.lightsleep(100)

    asyncio.run(main_task())

if __name__ == '__main__':

    #test_outputs()

    try:
        main()
    except KeyboardInterrupt:
        raise
    except Exception as e:
        print('unhandled-exception', e)
        time.sleep(1)
        raise e
        machine.reset()

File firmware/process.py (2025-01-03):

import math
import array
import gc
import time

import npyfile

from core import StateMachine, DataProcessor, empty_array

class GravitySplitter():

    def __init__(self, samplerate, lowpass_cutoff=0.5):

        rc = 1.0/(2*3.14*lowpass_cutoff)
        dt = 1.0/samplerate
        self.lowpass_alpha = rc / (rc + dt)

        self.gravity = None
        self.motion = array.array('f', [0, 0, 0])

    def process(self, xyz):
        assert len(xyz) == 3, xyz

        if self.gravity is None:
            # jump straigth to it, to avoid slow ramp-in
            self.gravity = array.array('f', xyz)
        
        a = self.lowpass_alpha
        for i in range(len(xyz)):
            self.gravity[i] = (a * self.gravity[i]) + ((1.0 - a) * xyz[i])
            self.motion[i] = xyz[i] - self.gravity[i]



def read_data_file(path,
        chunk_length,
        n_features=3,
        skip_samples=0,
        limit_samples=None):

    with npyfile.Reader(path) as data:

        # Check that data is expected format: files x timesteps x features, int16
        shape = data.shape
        assert len(shape) == 2, shape
        assert shape[1] == n_features, shape
        assert data.itemsize == 2, data.itemsize
        assert data.typecode == 'h', data.typecode

        # Read one chunk at a time
        sample_count = 0

        chunk_size = n_features*chunk_length
        data_chunks = data.read_data_chunks(chunk_size, offset=n_features*skip_samples)

        for arr in data_chunks:
            yield arr

            sample_count += 1
            if limit_samples is not None and sample_count > limit_samples:
                break


def process_file(path):

    samplerate = 50
    hop_length = 50
    window_length = hop_length

    x_values = empty_array('h', hop_length)
    y_values = empty_array('h', hop_length)
    z_values = empty_array('h', hop_length)

    p = DataProcessor()
    sm = StateMachine(time=0.0)

    n_axes = 3
    sample_no = 0
    for xyz in read_data_file(path, chunk_length=hop_length):
        t = (1.0/samplerate) * sample_no
        n_samples = len(xyz) // n_axes
        for i in range(n_samples):
            x_values[i] = xyz[(i*3)+0]
            y_values[i] = xyz[(i*3)+1]
            z_values[i] = xyz[(i*3)+2]

        motion, brushing = p.process(x_values, y_values, z_values)
        sm.next(t, motion, brushing)
        sample_no += n_samples

        yield t, motion, brushing, sm.state, sm.brushing_time


def test_process_happy():

    # FIXME: select a file with test data for success scenario
    data_path = ''
    for out in process_file(data_path):
        t = out[1]
        state = out[4]
        if state == 'done':
            done_time = t
            break

    expect_done = 300
    assert done_time >= expect_done - 10
    assert done_time <= expect_done + 10

def main():

    import sys

    total_brushing_time = 0.0

    data_path = sys.argv[1]
    out_path = sys.argv[2]
    out_columns = ['time', 'motion', 'brushing', 'state', 'brushing_time']
    endline = '\n'
    delim = ','

    with open(out_path, 'w') as out:

        # Write header
        for i, c in enumerate(out_columns):
            out.write(c)
            if i != len(out_columns)-1:
                out.write(delim)
        out.write(endline)

        for res in process_file(data_path):
            t, motion, brushing, state, brushing_time = res
            print('toothbrush-state-out', res)

            assert len(res) == len(out_columns)
            for i, v in enumerate(res):
                out.write(str(v))
                if i != len(res)-1:
                    out.write(delim)
            out.write(endline)

            total_brushing_time = max(brushing_time, total_brushing_time)

        print('toothbrush-done', total_brushing_time)

if __name__ == '__main__':
    main()

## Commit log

2024-12-16 toothbrush: Sketch for simple TinyML HAR usecase
    [toothbrush-handle.FCStd]
2024-12-20 toothbrush: Happy case passes
2024-12-20 toothbrush: Initial device code
    Can read accelerometer data
2024-12-20 toothbrush: Allow return to sleep without fail
    [main.py]
2024-12-20 toothbrush: Overall business logic tested on device
2024-12-20 toothbrush: Some slightly buggy progress indication
    [main.py]
2024-12-21 toothbrush: Revision 2 of handle
    Has attachment mechanism for brush, using zipties
    Missing a cover
    [toothbrush-handle.FCStd]
2024-12-28 toothbrush: Improve file organization
    [toothbrush-handle.FCStd]
2024-12-29 toothbrush: Load labels
    [project-6-at-2024-12-29-18-44-7f3d5ce7.csv]
2024-12-30 toothbrush: Integrate brushing classifier v1
    Seems to work, but very trigger happy
    Possibly because there is not any energetic-but-not-brushing data in dataset
    [brushing.csv]
2024-12-31 toothbrush: Initial custom data
    Labels need to be aligned with sensor data
    [project-7-at-2024-12-31-21-47-f2ebdbfe.csv]
2025-01-01 toothbrush: Some progress on merging labels and sensor data
    [project-7-at-2024-12-31-23-50-84589958.csv, videos.csv]
2025-01-01 toothbrush: Align the labels
    [videos.csv]
2025-01-02 toothbrush: Update 3d model
    [toothbrush-handle.FCStd]
2025-01-02 toothbrush: Start of evaluation code
    [brushing.csv]
2025-01-02 toothbrush: Update to model trained on 50 samples window
    [brushing.csv]
2025-01-03 toothbrush: Update 3d file
    [toothbrush-handle.FCStd]
2025-01-03 stand: Initial concept sketch
    [toothbrush-stand.FCStd]
2025-01-03 stand: A bit more clear
    [toothbrush-stand.FCStd]
2025-01-03 stand: Needs more space internally
    [toothbrush-stand.FCStd]
2025-01-03 stand: More work
    Should have been made with lofts..
    [toothbrush-stand.FCStd]
2025-01-03 stand: Redesign with flat sides
    [toothbrush-stand.FCStd]
2025-01-03 handle: Shorten by 12 mm
    M5StickC is now 4 mm from edge instead of 6mm
    This should make it possible to use a USB-C magsafe like quick-connect
    [toothbrush-handle.FCStd]
2025-01-03 stand: Update toothbrush reference
    [toothbrush-stand.FCStd]
2025-01-03 firmware: Fix model lookup
    [brushing.trees.csv]
2025-01-03 firmware: Unhardcode fail time, handle exceptions
    [core.py, main.py]
2025-01-03 firmware: Reset filters on done/fail
    Hopefully avoids going straight into brushing
    [core.py]
2025-01-03 firmware: Show bit of light on LED in idle state
2025-01-04 README: Update with more docs and images
    [toothbrush-handle-print.stl]
2025-01-24 mechanics: Add two concepts based on dollarml boards
    [toothbrush-dml20m.FCStd, toothbrush-dml21m.FCStd]
2025-01-25 mechanics: Add concept sketch for flexible
    [toothbrush-dml21m2.FCStd]
2025-02-08 mechanics: Initial attempt at flex/TPU attachment method
    [toothbrush-flex.FCStd]
2025-02-08 mechanics: Concept v2 for flex attachment
    [toothbrush-flex.FCStd]
2025-08-03 flex: Update design, try fix XIAO
    [toothbrush-flex.FCStd]
2025-08-03 firmware: Trying to run MicroPython on XIAO BLE
    Currently not finding a PWM output,
    and filesystem access with mpremote fails with OSError 2
    [make_vfs.py]
2025-08-09 buzzer_music: Try make Zephyr compatible
    [buzzer_music.py]
2025-08-09 TEMP: disable model
    .mpy files do not work on Zephyr build atm
    [core.py]
2025-08-10 Revert "TEMP: disable model"
    This reverts commit 8bd5e74bd22bac57c2af4726ba250629ed8834bb.
    [core.py]
2025-08-10 xiao: Fix running of model
    [core.py]
2025-08-15 mechanics: Try flex with overlapping fingers
    [toothbrush-flex.FCStd]
2025-08-31 xiao: WIP accelerometer driver
2025-09-19 xiao: FIFO runs - might be wrong wrt gyro+accel
    [core.py, main.py]
2025-09-20 xiao: Reset LSM6 on startup, set FIFO rounding mode
    [main.py]
2025-09-20 xiao: Fix deinterleaving of accelerometer data only
    [main.py]
2025-09-21 Switch over to pyproject.toml from requirements.txt
2025-10-04 firmware: Try fix running on M5Stick C PLUS 2
    Runs, but does not seem to trigger
    [main.py]
2025-10-04 firmware: Fix samples ignored
    Would not enter brushing state on M5StickC PLUS 2
    [main.py]
2025-10-04 firmware: Fix buzzer on XIAO
    Cannot use PWM for LED at same time
    [core.py, main.py]
2025-10-04 xiao: Use 52hz
    As close to 50 as we get
2026-01-01 dataset: Also load gyro data
2026-01-01 Add complimentary filter
    Better at picking up fine changes/variations in orientation
    But requires a gyro
